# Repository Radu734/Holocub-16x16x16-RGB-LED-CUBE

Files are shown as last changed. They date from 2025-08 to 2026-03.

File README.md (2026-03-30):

# **Holocub V2 – 16×16×16 RGB LED Cube**

*A fully addressable 3D LED display for animations, games, and visual effects.*

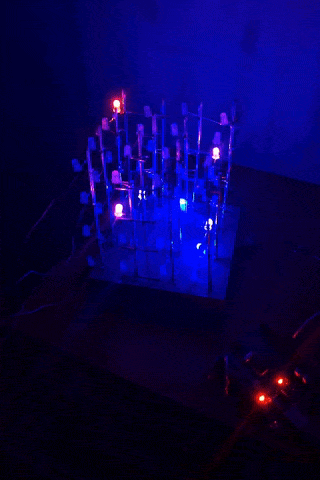
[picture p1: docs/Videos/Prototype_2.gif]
LED Cube Example


---

## 📜 Overview
Holocub V2 is a large-scale **16×16×16 RGB LED cube** (4096 voxels total) built with WS2812B addressable LEDs.  
It is designed to display dynamic animations, interactive effects, and data visualizations in 3D.

The cube is controlled by a microcontroller (planned: **RPi Pico 2W / other capable MCU**) and supports both **procedural animations** and **pre-rendered frames** loaded from an SD card.

---

## 🔧 Hardware Specifications

| Component | Specification |
|---|---|
| **Cube Size** | 16 × 16 × 16 voxels |
| **Total LEDs** | 4096 WS2812B RGB LEDs |
| **LED Type** | WS2812B (5V, individually addressable) |
| **PSUs** | 4 × 5v 350w |
| **Data Lines** | One per 16×16 vertical layer (16 total) |
| **LED Strip Arrangement** | Snake layout per layer (serpentine wiring) |
| **MCU** | Raspberry Pi Pico 2W (planned) / Teensy 4.1 (more power but no internal BLE and wifi) |
| **Storage** | MicroSD card (frame/animation storage) |
| **Power Injection** | Multiple injection points per strip |
| **Estimated Max Power** | ~1.23 kW at full white (theoretical max) |

---

# HoloBoard – PCB by Dragoș

**Short description**  
HoloBoard is a custom PCB designed for the Holocub project, acting as the main control and interface board.  
It hosts a Raspberry Pi Pico 2W, integrates a piezo buzzer, and features two bidirectional logic-level shifters for for the communication between the pico and the WS2812B as 3v3 logic could cause interference.

## 🔧 Key Features
- **MCU Slot:** Raspberry Pi Pico 2W header footprint (solder-in or socket).
- **Audio Output:** 1 × piezo buzzer connector (with optional series resistor).
- **Expandable hardware:** Left over pins (used mainly for I²C and SPI) routed to the side for extra connectivity.
- **Build Quality:** Silk labels for pins, test pads, and mounting holes.
- **Filter capacitors:** 2 filter caps for main power connection and 1 for each logic level shofter for optimal data transmission without interference.

## 📦 Minimal BOM
- 1 × RP2040 (Pico 2W) socket / header footprint
- Headers, pads, mounting hardware
- Yet to add more info

---

## 📜 Schematics & Photos

### **Schematic – Level Shifter**
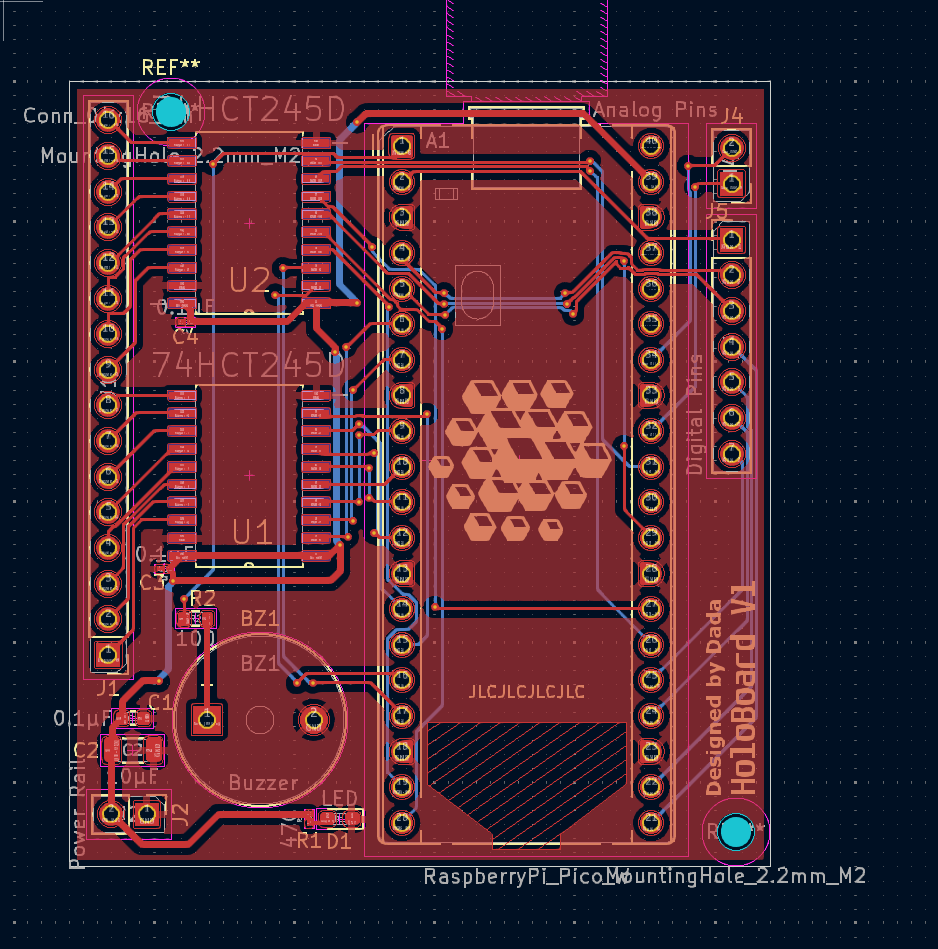
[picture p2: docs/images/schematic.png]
HoloBoard schematic
  
*Figure 1 — The HoloBoard schematic in KeyCad.*

### **Schematic – Power & Buzzer**
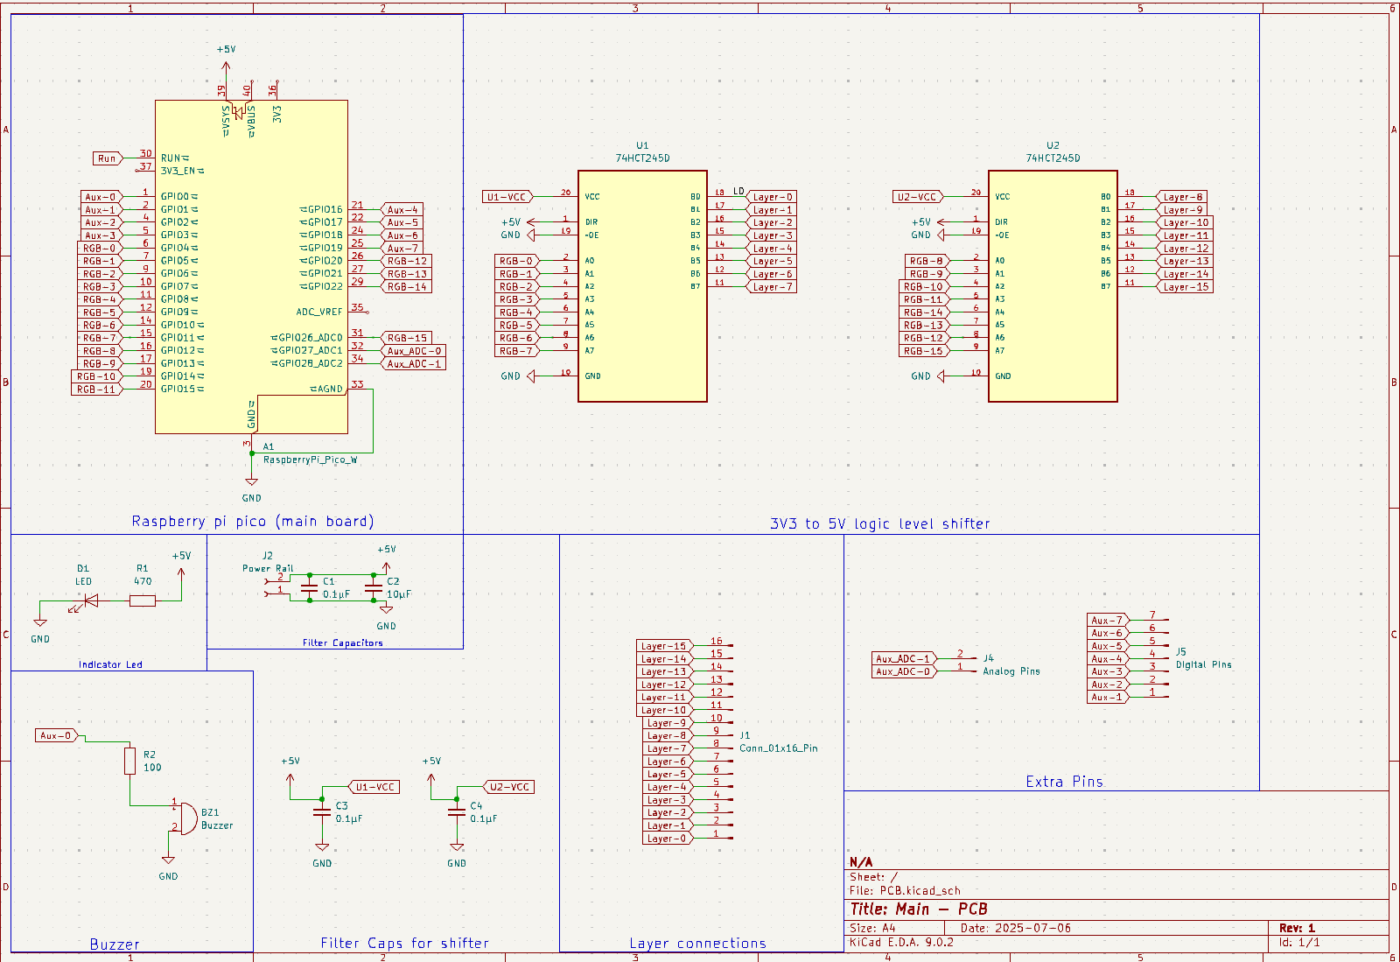
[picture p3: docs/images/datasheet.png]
HoloBoard datasheet
  
*Figure 2 — components used, I/O's, connections.*

### **Photo – Assembled (Front)**
HoloBoard assembled — front  
*Figure 3 — Front view, Pico 2W inserted.*

### **Photo – Assembled (Back / Solder Side)**
HoloBoard assembled — back  
*Figure 4 — Back view showing soldering and Logo.*

---

## 🚀 Features
- **Scalable architecture** – animations work on both 4×4×4 test cube and full 16×16×16 cube. 
- **Voxel-based rendering** – uses a global `voxelMatrix[x][y][z]` buffer for color control.
- **Procedural animations** – gradients, bouncing “DVD logo” effect, rain simulation, waves.
- **Pre-rendered playback** – read `.vox` file for animations or custom binary format.
- **Custom GFX library** – draw lines, planes, waves, text in 3D space.
- **SD card support** – load animations without reflashing firmware.
- **Multi-PSU design** – independent PSU per cube tower for stable power delivery.
- **Website based animation upload and debug** - Upload animations or images directly from a computer to the Holocube.

---

## ⚡ Power & Safety Notes
- WS2812B LEDs consume up to **60 mA per LED** at full brightness (white).
- Theoretical maximum current: **~245 A total** across 4 PSUs.
- Always fuse PSU outputs and use thick wiring for high-current paths.
- Avoid running full white at 100% brightness for prolonged periods to reduce heat.

---

## 🖥️ Software Workflow
### **Procedural animations**
- Written in C++ inside `/animations`
- Rendered directly to `voxelMatrix`
- Useful for dynamic effects and parameterized visuals

### **Pre-rendered animations**
- Created in Paint, MagicaVoxel, or similar tools
- Exported as `.bmp` or custom `.hca` (Holocub Animation) binary format
- Loaded via SD card at runtime

---

## 📸 Development Timeline
- **Phase 1** – Test code, Custom PCB `HoloBoard`, SD card reader on 4×4×4 cube ✅
- **Phase 2** – Develop GFX & cube configuration libraries ✅
- **Phase 3** – Build cube structure & solder all LED strips 🔄
- **Phase 4** – Integrate procedural + SD-based playback
- **Phase 5** – Optimize power, stability, and animation library

---

## 🛠️ Setup & Build
### **Dependencies**
- [Adafruit NeoPixel](https://github.com/adafruit/Adafruit_NeoPixel)
- SD card library for chosen MCU
- C++17 compatible toolchain
- PlatformIO (recommended) or Arduino IDE

### **Compilation**
```bash
# PlatformIO
pio run --target upload
```

### **Arduino IDE**
- Install Adafruit NeoPixel library
- Select **Raspberry Pi Pico 2W** (or your MCU)
- Upload `src/main.ino`

---

## 📄 License
[MIT License](LICENSE) – You are free to use, modify, and distribute this project with attribution.

---

## 🙌 Credits
- **Core team:** [Bernea Dragoș Dada & Teodosiu Radu]
- **Special thanks:** MaltWiskey (inspiration & reference designs), Adafruit (NeoPixel library) and the C++ community.
- **Open Source softwares used for the cube animations:** MagicaVoxel (3D sprites designer)

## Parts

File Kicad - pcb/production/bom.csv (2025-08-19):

Designator | Footprint | Quantity | Value | LCSC Part #
A1 | RaspberryPi_Pico_Common_THT | 1 | RaspberryPi_Pico_W
BZ1 | Buzzer_12x9.5RM7.6 | 1 | Buzzer
C1 | 0603 | 1 | 0.1 µF
C2 | 1206 | 1 | 10 µF
C3, C4 | 0201 | 2 | 0.1 µF
D1 | 0603 | 1 | LED
J1 | PinHeader_1x16_P2.54mm_Vertical | 1 | Conn_01x16_Pin
J2 | PinHeader_1x02_P2.54mm_Vertical | 1 | Power Rail
J4 | PinHeader_1x02_P2.54mm_Vertical | 1 | Analog Pins
J5 | PinHeader_1x07_P2.54mm_Vertical | 1 | Digital Pins
R1 | 0201 | 1 | 470
R2 | 0603 | 1 | 100
U1, U2 | SOIC127P1032X265-20N | 2 | 74HCT245D | 74HCT245D

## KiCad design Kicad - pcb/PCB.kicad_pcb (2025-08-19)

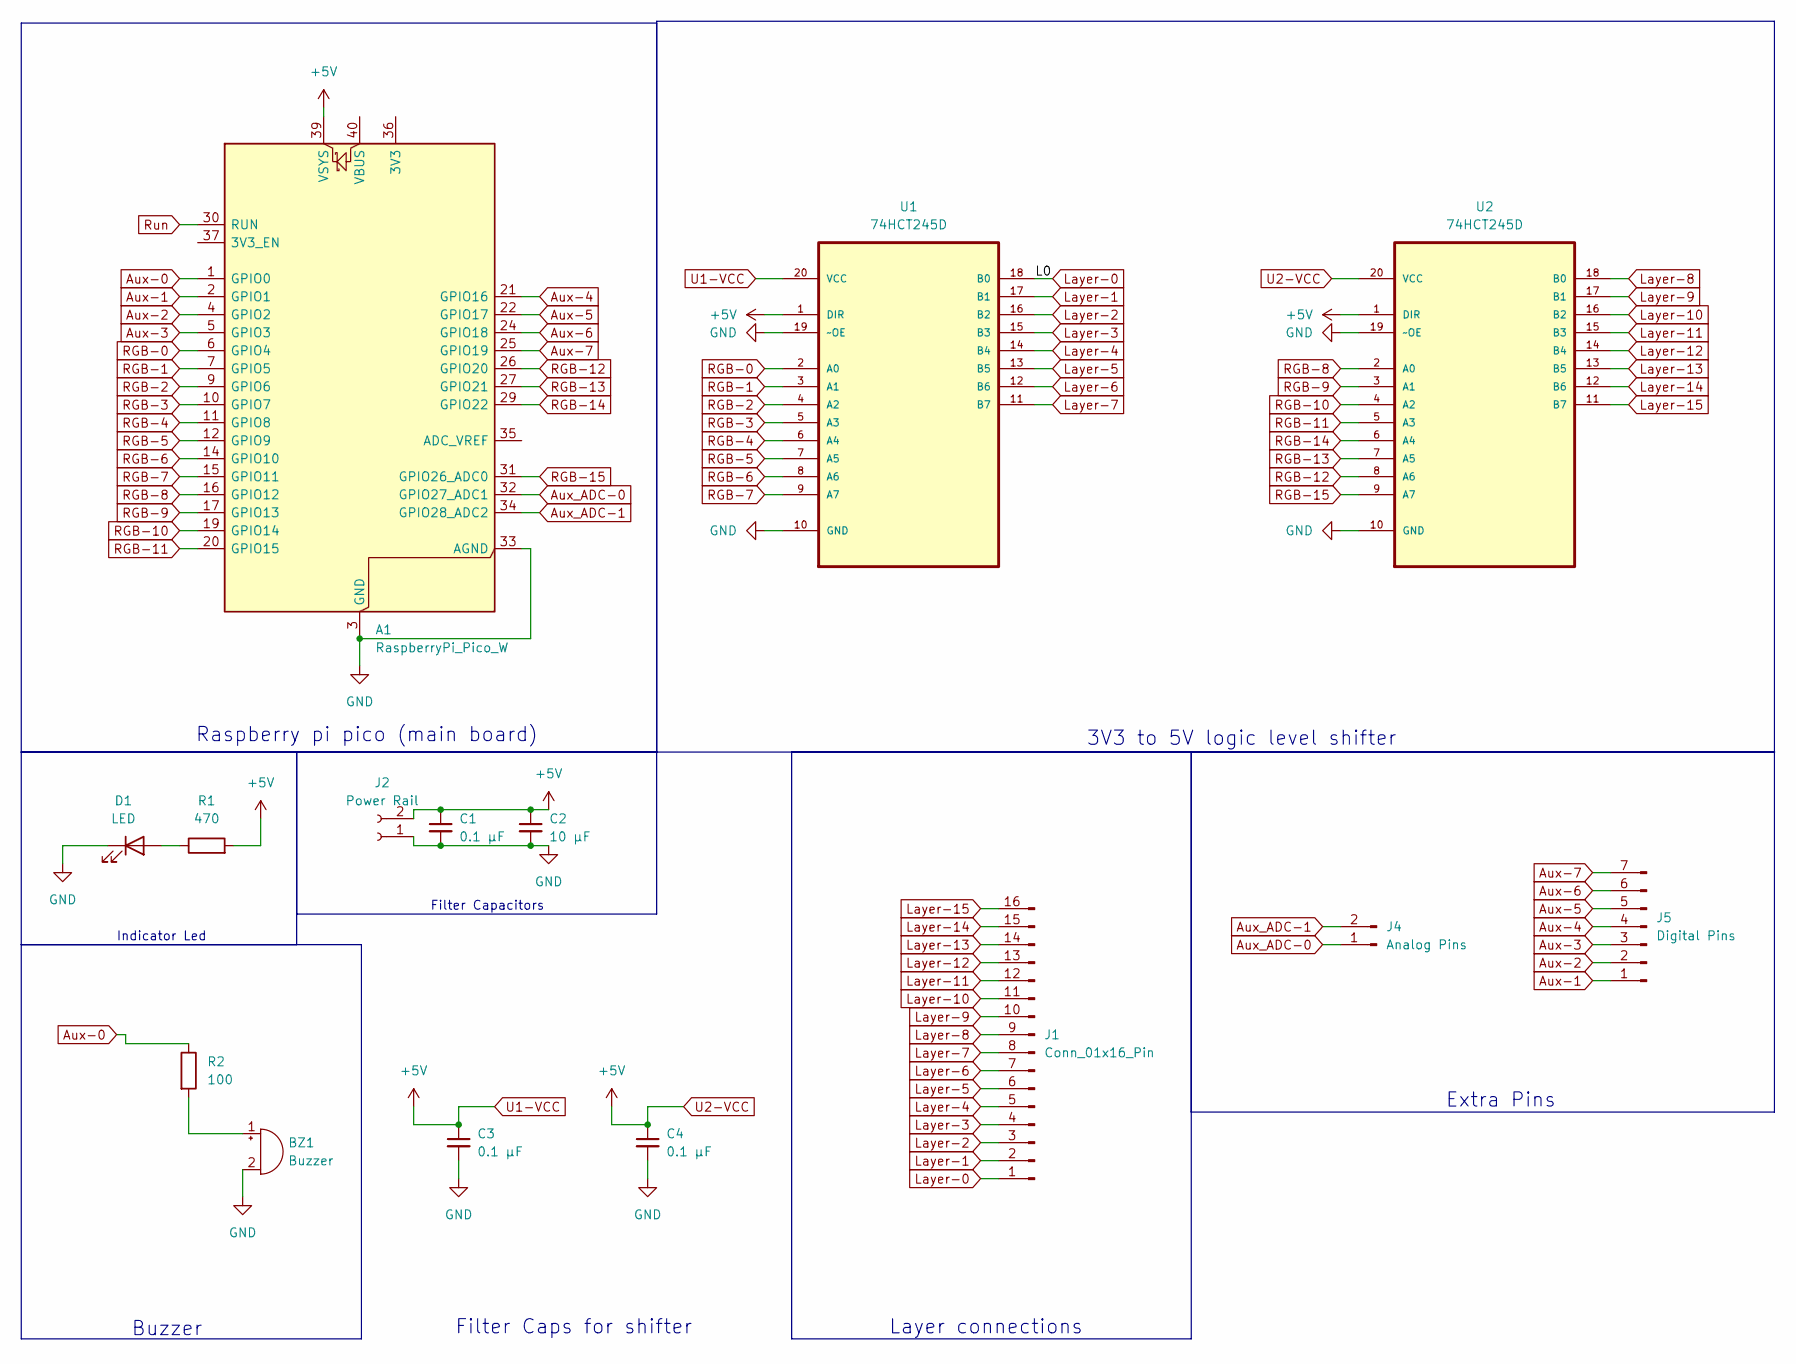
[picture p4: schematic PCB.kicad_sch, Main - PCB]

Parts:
A1: RaspberryPi_Pico_W; RaspberryPi_Pico_Common_THT
BZ1: Buzzer; Buzzer_12x9.5RM7.6
C1: 0.1 µF; C_0603_1608Metric
C2: 10 µF; C_1206_3216Metric
C3, C4: 0.1 µF; C_0201_0603Metric
D1: LED; LED_0603_1608Metric_Pad1.05x0.95mm_HandSolder
J1: Conn_01x16_Pin; PinHeader_1x16_P2.54mm_Vertical
J2: Power Rail; PinHeader_1x02_P2.54mm_Vertical
J4: Analog Pins; PinHeader_1x02_P2.54mm_Vertical
J5: Digital Pins; PinHeader_1x07_P2.54mm_Vertical
R1: 470; R_0201_0603Metric
R2: 100; R_0603_1608Metric
U1, U2: 74HCT245D; SOIC127P1032X265-20N; MPN 74HCT245D

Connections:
Aux-0: A1.1 (GPIO0), R2.1
Aux-1: A1.2 (GPIO1), J5.1
Aux-2: A1.4 (GPIO2), J5.2
Aux-3: A1.5 (GPIO3), J5.3
Aux-4: A1.21 (GPIO16), J5.4
Aux-5: A1.22 (GPIO17), J5.5
Aux-6: A1.24 (GPIO18), J5.6
Aux-7: A1.25 (GPIO19), J5.7
Aux_ADC-0: A1.32 (GPIO27_ADC1), J4.1
Aux_ADC-1: A1.34 (GPIO28_ADC2), J4.2
GND: A1.3 (GND), A1.8 (GND), A1.13 (GND), A1.18 (GND), A1.23 (GND), A1.28 (GND), A1.33 (AGND), A1.38 (GND), BZ1.2 (-), C1.2, C2.2, C3.2, C4.2, D1.1 (K), J2.1, U1.10 (GND), U1.19 (~OE), U2.10 (GND), U2.19 (~OE)
Layer-0: J1.1, U1.18 (B0)
Layer-1: J1.2, U1.17 (B1)
Layer-2: J1.3, U1.16 (B2)
Layer-3: J1.4, U1.15 (B3)
Layer-4: J1.5, U1.14 (B4)
Layer-5: J1.6, U1.13 (B5)
Layer-6: J1.7, U1.12 (B6)
Layer-7: J1.8, U1.11 (B7)
Layer-8: J1.9, U2.18 (B0)
Layer-9: J1.10, U2.17 (B1)
Layer-10: J1.11, U2.16 (B2)
Layer-11: J1.12, U2.15 (B3)
Layer-12: J1.13, U2.14 (B4)
Layer-13: J1.14, U2.13 (B5)
Layer-14: J1.15, U2.12 (B6)
Layer-15: J1.16, U2.11 (B7)
unnamed: BZ1.1 (+), R2.2
unnamed: D1.2 (A), R1.1
RGB-0: A1.6 (GPIO4), U1.2 (A0)
RGB-1: A1.7 (GPIO5), U1.3 (A1)
RGB-2: A1.9 (GPIO6), U1.4 (A2)
RGB-3: A1.10 (GPIO7), U1.5 (A3)
RGB-4: A1.11 (GPIO8), U1.6 (A4)
RGB-5: A1.12 (GPIO9), U1.7 (A5)
RGB-6: A1.14 (GPIO10), U1.8 (A6)
RGB-7: A1.15 (GPIO11), U1.9 (A7)
RGB-8: A1.16 (GPIO12), U2.2 (A0)
RGB-9: A1.17 (GPIO13), U2.3 (A1)
RGB-10: A1.19 (GPIO14), U2.4 (A2)
RGB-11: A1.20 (GPIO15), U2.5 (A3)
RGB-12: A1.26 (GPIO20), U2.8 (A6)
RGB-13: A1.27 (GPIO21), U2.7 (A5)
RGB-14: A1.29 (GPIO22), U2.6 (A4)
RGB-15: A1.31 (GPIO26_ADC0), U2.9 (A7)
Run: A1.30 (RUN)
U1-VCC: A1.39 (VSYS), C1.1, C2.1, C3.1, C4.1, J2.2, R1.2, U1.1 (DIR), U1.20 (VCC), U2.1 (DIR), U2.20 (VCC)

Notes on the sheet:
Extra Pins
3V3 to 5V logic level shifter
Filter Caps for shifter
Indicator Led
Filter Capacitors
Layer connections
Buzzer
Raspberry pi pico (main board)

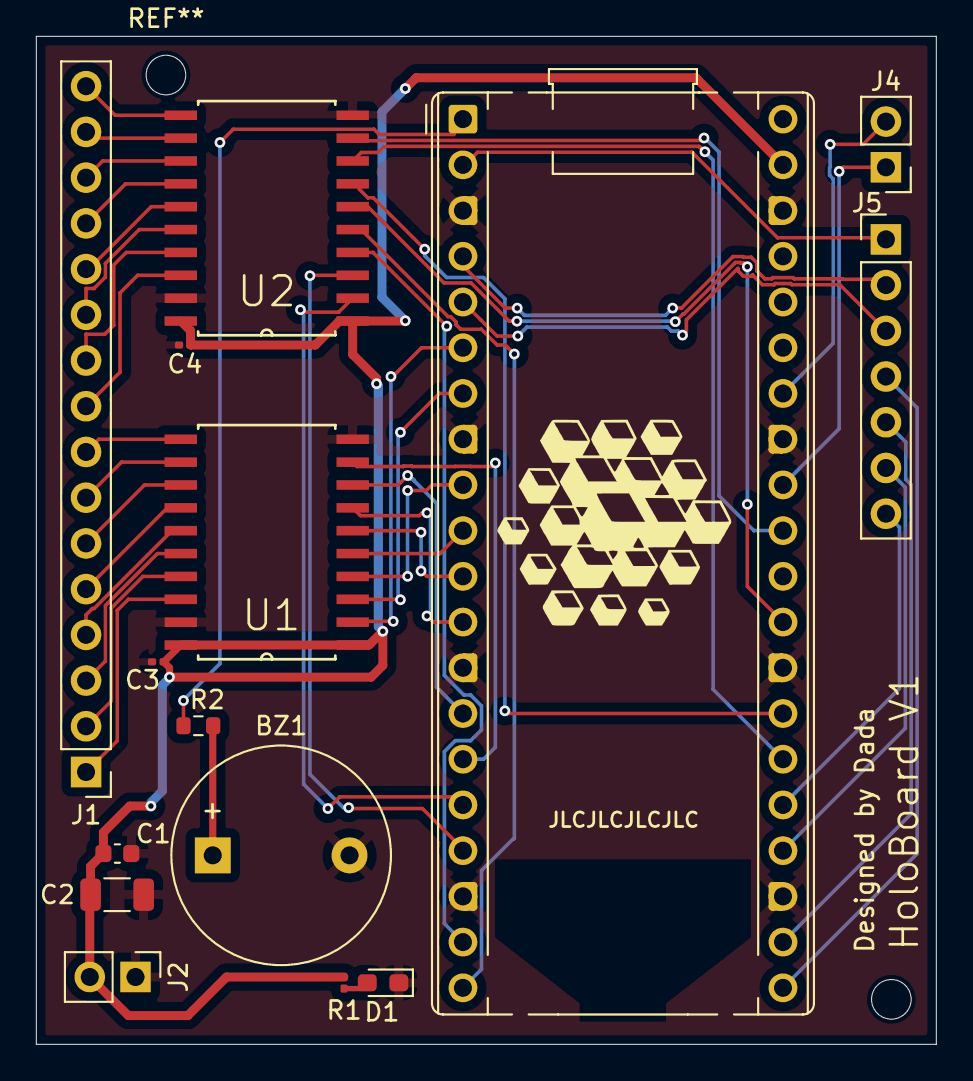
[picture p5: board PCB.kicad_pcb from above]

Board: 4 copper layers, 50.0 x 56.0 mm, 15 parts (0 on the bottom side), 46 nets.

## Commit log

2025-08-17 Added PCB Gerber Files
    [PCB-B_Mask.gbs, PCB-B_Paste.gbp, PCB-B_Silkscreen.gbo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]
2026-03-30 Replace video link with GIF for LED Cube example
    Updated the LED Cube example image to a GIF format.
